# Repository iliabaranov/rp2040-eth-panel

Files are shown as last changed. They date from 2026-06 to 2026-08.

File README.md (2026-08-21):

# rp2040-eth-panel

Network-connected **two-button / dual-WS2812-ring operator panel** on a **Waveshare
RP2040-ETH** board. Debounces the buttons and streams press/release events over Ethernet
as line-delimited JSON; the host drives the two 16-LED rings and the illuminated
button's lamp over the same socket — with **robust firmware updates over Ethernet**
(no USB or physical access needed after the one-time install).

- **Board:** Waveshare RP2040-ETH (RP2040 + CH9120 UART↔Ethernet bridge; 4 MB flash)
- **Firmware:** C11 / Raspberry Pi Pico SDK 2.1.1
- **Network:** DHCP, TCP server on port 5005, line-delimited JSON
- **Inputs:** 2 momentary buttons (button 1 illuminated), 30 ms debounce (runtime-configurable)
- **Outputs:** 2× 16-LED WS2812 rings (color + brightness), button-1 lamp on/off (GP6)
- **OTA:** immutable bootloader + single app slot + network recovery (CRC32-verified)

The panel is a **host-commanded peripheral**: rings and lamp power up dark and the host
(normally the ROS 2 driver) re-sends desired state on every connect — see
[`docs/DESIGN.md`](docs/DESIGN.md) for why nothing is persisted to flash. Sibling
project of [`rp2040-eth-keypad`](../rp2040-eth-keypad) (same board, same OTA stack).

See [`docs/DESIGN.md`](docs/DESIGN.md), [`docs/OTA.md`](docs/OTA.md),
[`docs/BRINGUP.md`](docs/BRINGUP.md), and the CH9120/board datasheets in
[`docs/`](docs/).

## Repository layout
```
firmware/     the Pico SDK build (CMake root); COLCON_IGNORE keeps colcon out of it
  src/          application: net (CH9120), buttons, rings, status LED, protocol, ota
  bootloader/   immutable first-stage bootloader (boot select + OTA recovery receiver)
  linker/       app (0x10040000) and bootloader (0x10000000, 256 KB) memory maps
ros2/panel_driver/   ROS 2 (Humble) driver: button topics in, ring/lamp topics out
examples/     standalone single-file ROS 2 driver (run directly — no colcon build)
test/         pytest + ctypes tests for the pure logic (buttons/rings/protocol) + OTA sim
tools/        flash / monitor / OTA / provision / live & mock helpers
```

## Prerequisites
Pico SDK (`PICO_SDK_PATH` set), the ARM toolchain (`arm-none-eabi-gcc`), CMake, and
`picotool` **built with USB support** (needs `libusb-1.0-dev`; a `99-picotool.rules` udev
rule for VID `2e8a` enables non-root access). Python 3 + `pyserial` for the host tools.

On this machine the toolchain lives at:
```bash
export PICO_SDK_PATH=~/pico/pico-sdk
export PATH=~/pico/xpack-arm-none-eabi-gcc-13.2.1-1.1/bin:~/.local/bin:$PATH   # GCC 13.2 + picotool 2.1.1
```

## Build
```bash
cmake -S firmware -B build   # one-time configure
cmake --build build -j       # -> build/{bootloader,panel,apptest}.uf2 (+ .bin)
```

## Install (one time, over USB)
Flashes the immutable bootloader (`0x10000000`) + application (`0x10040000`). After this,
all firmware updates go over Ethernet.
```bash
tools/provision.sh          # forces BOOTSEL, loads both stages, reboots
```
If the board can't be reached (blank flash, no app), hold the **BOOTSEL** button while
plugging in USB, then run `tools/provision.sh`. On boot the WS2812 LED flashes the IP's
last octet (green = DHCP).

## Bench test (no network): RING_SELFTEST
```bash
cmake -S firmware -B build -DRING_SELFTEST=1 && cmake --build build -j && tools/flash.sh --no-build
```
Skips networking and cycles pure logical **RED 1 s → GREEN 2 s → BLUE 4 s** on both
rings — the distinct dwell times identify which channel is which, so a GRB/RGB swap is
obvious (fix via `RING_COLOR_ORDER_GRB` in `firmware/src/config.h`). Raw button edges echo on
USB serial and the lamp follows button 1, so the whole panel is verifiable with just
USB power. Rebuild without the flag for the normal firmware.

## Watch events / drive the panel live
Quickest way to confirm the panel works over Ethernet. Pure-Python stdlib, no ROS:
```bash
tools/panel_live.py <device-ip>      # e.g. tools/panel_live.py 10.74.29.13
```
Prints each button down/up as it happens **and** takes interactive ring/lamp commands
(e.g. set ring 1 red, lamp on) so both directions of the protocol are exercised from
one terminal. `tools/panel_watch.py` is the watch-only variant for passive logging. The
device IP is shown on USB serial and encoded by the WS2812 (last octet). (No hardware
yet? `tools/mock_panel_server.py` emits the same protocol on `127.0.0.1:5005`.)

> The CH9120 is a **single-client** TCP server — disconnect `panel_live.py` before
> starting the ROS driver (and vice versa); a second socket wedges the bridge.

## Update firmware over Ethernet (OTA)
```bash
cmake --build build -j                                  # build the new image
tools/ota_flash.py --host <device-ip> build/panel.bin
```
This asks the running app to reboot into recovery, streams the image in CRC-checked
chunks, verifies the whole image, and reboots into it — no USB, no buttons. A failed or
interrupted update can't brick the device: the immutable bootloader stays in network
recovery for a re-push (`--in-recovery` skips the app trigger).

The transfer is resilient to the CH9120's frameless byte-stream quirks: both ends
**resync to known token boundaries** (so stray/stale bytes from a dropped connection
can't desync the session), corrupt chunks are re-sent locally, and the whole flash
auto-retries on a fresh connection if the link blips (`--retries`, default 3). See
[`docs/OTA.md`](docs/OTA.md) → *Transport robustness*.

## Status LED (onboard WS2812, GP25)
| Color | Meaning |
|---|---|
| blue (solid) | app booted, bringing up the network |
| green, flashing digits | app running, **DHCP** mode (digits = IP's last octet) |
| amber, flashing digits | app running, **static** mode (digits = IP's last octet) |
| purple (solid) | bootloader recovery — waiting for / receiving an OTA |

> The color reflects the **configured IP mode**, not a live Ethernet link. The CH9120
> exposes no link/DHCP status to the RP2040 (its `LINK` pin drives the RJ45 jack LEDs,
> not a GPIO), and returns a cached IP even with no cable — so firmware can't detect
> "cable attached." Set the mode for your network via `NET_USE_DHCP` in `firmware/src/config.h`
> (no auto-fallback).

## ROS 2 driver (Humble)
[`ros2/panel_driver/`](ros2/panel_driver/) connects to the device's TCP/JSON server and
bridges it to topics:

| Topic | Type | Direction | Notes |
|---|---|---|---|
| `~/button1/pressed` | `std_msgs/Bool` | publish | latched (transient local) |
| `~/button2/pressed` | `std_msgs/Bool` | publish | latched (transient local) |
| `~/ring1/color` | `std_msgs/ColorRGBA` | subscribe | `a` = brightness 0..1 |
| `~/ring2/color` | `std_msgs/ColorRGBA` | subscribe | `a` = brightness 0..1 |
| `~/button1/light` | `std_msgs/Bool` | subscribe | illuminated button's lamp |

Parameters: `host`, `port` (default 5005), `reconnect_period`.

> **Warning:** `ColorRGBA.a` defaults to **0**, which means brightness 0 — a message
> with only `r/g/b` set shows nothing. Always set `a` (1.0 = full).

The driver owns desired state: it caches the last commanded ring colors and lamp state
and **re-sends them whenever the device reconnects** (every `hello` triggers this;
the driver waits ~1 s for the device's connect-time hello and requests one itself
if it doesn't arrive — it never fires on CH9120 batches whose TCPS status pin is
dead).

The driver also supervises the link itself: the CH9120 silently drops a displaced
client (no FIN/RST), which strands a naive client on a half-open socket. The driver
pings after 2 s of RX silence and declares the connection dead after 6 s without
**receiving** anything (`keepalive_period` / `liveness_timeout` parameters), then
reconnects and resyncs automatically — no manual restarts. Note this supervises but
does not repeal the single-client rule: two drivers pointed at one panel will
endlessly steal the slot from each other, visibly, in both logs. The firmware deliberately persists
nothing — see [`docs/DESIGN.md`](docs/DESIGN.md). Single TCP client only: stop
`panel_live.py` (and any other driver) before launching the driver.

### Standalone example (no build)
For a minimal, copy-pasteable starting point, [`examples/standalone_panel_driver.py`](examples/standalone_panel_driver.py)
is a ~100-line single-file driver you run directly — no colcon build, no package, no
launch file:
```bash
source /opt/ros/humble/setup.bash
python3 examples/standalone_panel_driver.py <device-ip>
ros2 topic echo /button1_pressed          # plain names: /button{1,2}_pressed, /ring{1,2}_color, /button1_light
```
It publishes only on a press (no latched startup state), so `echo` stays quiet until you
press. Use the `panel_driver` package above for production (auto-reconnect, desired-state
resync, latched state, clean shutdown).

## Tests
```bash
tools/test.sh      # fast: pure-logic host lib + pytest (buttons/rings/protocol)
tools/test_ota.sh  # OTA stress: real flasher vs. device+CH9120 simulator, fault-injected
```
`tools/test_ota.sh` runs hundreds of OTA pushes through a faithful CH9120-bridge
simulator with injected stale bytes, mid-transfer resets, and byte loss — the
regression guard for the transport-desync bug (multi-minute by design, no hardware).

## Recovery
- **App update failed / device in recovery:** re-run `tools/ota_flash.py` (it auto-detects
  recovery), or push with `--in-recovery`.
- **Device unresponsive:** press **RESET** (RUN button) to reboot into the last valid app.
- **Re-provision / bootloader update:** hold **BOOTSEL**, replug USB, run `tools/provision.sh`.
  USB BOOTSEL (mask ROM) is always available as the ultimate fallback.

## License
Apache License 2.0 — see [`LICENSE`](LICENSE).

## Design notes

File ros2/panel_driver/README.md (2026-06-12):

# panel_driver (ROS 2 Humble)

ROS 2 **Humble** (`rclpy`) driver for the RP2040-ETH operator panel (2 buttons —
one illuminated — and 2×16 WS2812 LED rings). Connects as a TCP client to the device's
line-delimited JSON server and bridges it to ROS topics in both directions.

> **Single TCP client only.** The CH9120 Ethernet bridge wedges if a second
> client connects. Do **not** run `tools/panel_live.py` (or any other tool
> talking to port 5005) while this driver is running.

## Topics

All names are node-relative (`~/...`); with the default node name they appear
under `/panel_driver/...`.

### Published

| topic | type | QoS | meaning |
|---|---|-----|---|
| `~/button1/pressed` | `std_msgs/Bool` | RELIABLE, TRANSIENT_LOCAL, depth 1 | button 1 state (latched) |
| `~/button2/pressed` | `std_msgs/Bool` | RELIABLE, TRANSIENT_LOCAL, depth 1 | button 2 state (latched) |

Button states are **latched**: late subscribers immediately receive the current
state. Initial states come from the device's `hello` line (sent on every
connect); after that, every `down`/`up` edge is published.

### Subscribed

| topic | type | meaning |
|---|---|---|
| `~/ring1/color` | `std_msgs/ColorRGBA` | ring 1 color + brightness |
| `~/ring2/color` | `std_msgs/ColorRGBA` | ring 2 color + brightness |
| `~/button1/light` | `std_msgs/Bool` | button 1 lamp (the illuminated button) |

> **⚠ The `a` channel is BRIGHTNESS, and it defaults to 0.0!**
> `r`, `g`, `b` are 0..1; `a` is brightness 0..1 where **`a=0` means the ring
> is OFF**. `ColorRGBA` zero-initializes `a`, so a sender that only sets
> `r/g/b` turns the ring off. Always set `a` explicitly (e.g. `a: 1.0`).

## Desired-state resync

The driver caches the last commanded ring colors and lamp state. On every
`hello` — i.e. every (re)connect, which covers device reboots, OTA updates and
cable blips — it re-sends all cached commands, so the panel always converges to
ROS's desired state. Commands published while disconnected are cached and
applied on the next reconnect.

## Parameters

| param | default | meaning |
|---|---|---|
| `host` | `''` | device IP (DHCP-assigned). **Required** — the node logs a fatal error and exits if empty. |
| `port` | `5005` | device TCP port |
| `reconnect_period` | `2.0` | seconds between reconnect attempts |

## Run

```bash
# In a ROS 2 Humble workspace (ros2/ as the src dir):
source /opt/ros/humble/setup.bash
colcon build --packages-select panel_driver
source install/setup.bash

ros2 launch panel_driver panel_driver.launch.py host:=<device-ip>
# or:
ros2 run panel_driver panel_driver --ros-args -p host:=<device-ip>
```

Watch the buttons (latched — you get the current state immediately):

```bash
ros2 topic echo /panel_driver/button1/pressed
```

Set ring 1 to orange at half brightness (note `a` is set!):

```bash
ros2 topic pub --once /panel_driver/ring1/color std_msgs/msg/ColorRGBA \
  "{r: 1.0, g: 0.25, b: 0.0, a: 0.5}"
```

Turn the button lamp on:

```bash
ros2 topic pub --once /panel_driver/button1/light std_msgs/msg/Bool "{data: true}"
```

## Tests

The protocol logic is a pure module ([`panel_driver/panel_protocol.py`](panel_driver/panel_protocol.py),
no `rclpy` import) and is unit-tested without a ROS graph. Run the tests with a
clean environment — a sourced ROS env injects pytest plugins that break
collection:

```bash
cd ros2/panel_driver
PYTHONPATH= PYTEST_DISABLE_PLUGIN_AUTOLOAD=1 python3 -m pytest test/
```

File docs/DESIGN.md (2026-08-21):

# RP2040-ETH Panel Controller — Design

Network-connected **two-button / dual-WS2812-ring operator panel** on a **Waveshare
RP2040-ETH** board (RP2040 + CH9120 UART↔Ethernet bridge). Debounces the buttons and
streams press/release events to a TCP client as line-delimited JSON; the host commands
the two LED rings and the illuminated button's lamp over the same socket. Firmware is
updated over Ethernet (no USB/physical access after the one-time install) — see
[`OTA.md`](OTA.md). Port of the `rp2040-eth-keypad` project to a different front-panel
peripheral set (same board, network layer, status LED, and OTA stack).

## Requirements (locked)

| Decision | Choice |
|---|---|
| Panel hardware | 2 momentary buttons (button 1 illuminated, lamp output) + 2× WS2812 rings (16 LEDs each) |
| MCU / board | **Waveshare RP2040-ETH** (RP2040 + **CH9120** UART↔Ethernet bridge) |
| Firmware stack | C11, Raspberry Pi Pico SDK 2.1.1 (CH9120 driven over UART1; no Ethernet lib) |
| Transport | TCP **server** on the device, port 5005, single control client |
| Wire format | Line-delimited JSON (one object per `\n`-terminated line), both ways |
| IP addressing  | **DHCP** by default (`NET_USE_DHCP`); static is a compile-time option. No auto-fallback — the CH9120 exposes no link/lease status the RP2040 can read, so the mode is chosen explicitly. |
| Host side | ROS 2 (Humble) driver `ros2/panel_driver` owns desired ring/lamp state  |
| State | **Nothing persisted to flash** — see *No flash persistence* below |

## Hardware

### Buttons
- Two momentary buttons wired **to GND**, read with internal pull-ups → **active-low**.
  No external parts needed.
- Button 1 is an **illuminated** button; its lamp is driven separately from GP6.
- Debounce default **30 ms** (`DEBOUNCE_MS_DEFAULT`), runtime-overridable via the
  `config` command. The first sample after boot **seeds** the debouncer state without
  emitting an edge, so a button held during power-up doesn't fire a phantom event (its
  state still reaches the host in the `hello` line).

### WS2812 rings (2× 16 LEDs)
- **Power from 5 V** (header pin 1 = VBUS), not 3.3 V. Data line via a **~330 Ω series
  resistor** close to the first LED.
- 3.3 V data into a 5 V-powered ring usually works; if colors glitch or the first LED
  misbehaves, add a **level shifter** (e.g. 74AHCT125) on the data line.
- Put **~1000 µF** of bulk capacitance across each ring's power feed.
- **Power budget:** worst-case full-white is ~60 mA/LED → **≈960 mA per 16-LED ring at
  5 V** (~1.9 A both rings). Mind the USB/5 V supply budget; typical indicator colors at
  partial brightness draw far less.
- Color order is per-chain: standard WS2812B rings latch **GRB**
  (`RING_COLOR_ORDER_GRB=1` default); the board's **onboard GP25 LED anomalously
  latches RGB** (verified by self-test in the keypad project). See *WS2812 byte order*.

### Button-1 lamp (GP6)
GP6 is a plain on/off 3.3 V GPIO output. Driving the lamp directly is fine only for a
low-current 3.3 V LED (**≲10 mA**). If the illuminated button's lamp needs more
current, or runs at 5/12/24 V, use a **transistor/MOSFET low-side driver** (gate/base
from GP6 with a series resistor + pulldown, lamp supply to its own rail).

## Pin map (Waveshare RP2040-ETH)

Reserved by the CH9120 bridge (fixed by the board), do not reuse:

| Signal | GPIO | Notes |
|---|---|---|
| UART1 TX → CH9120 RXD | GP20 | RP2040 transmits config/data |
| UART1 RX ← CH9120 TXD | GP21 | RP2040 receives data |
| CFG | GP18 | LOW = config mode |
| RST | GP19 | Active-low reset |
| TCPS | GP17 | LOW = TCP peer connected |

**Header reality (RP2040-ETH MINI):** the 24-pin header (P1) only breaks out
**GPIO0–9, 22, 26, 27, 28** (+ power/RUN). GP10–15 and GP25 are *not* on the header;
GP16–21 are the CH9120. Application pins are chosen from the broken-out set:

| Function | GPIO | Header pin | Notes |
|---|---|---|---|
| Ring 1 data | GP2 | 21 | via ~330 Ω series resistor |
| Ring 2 data | GP3 | 20 | via ~330 Ω series resistor |
| Button 1 | GP4 | 19 | illuminated button, to GND, internal pull-up (active-low) |
| Button 2 | GP5 | 18 | to GND, internal pull-up (active-low) |
| Lamp (button 1) | GP6 | 16 | plain on/off output, 3.3 V — see drive note above |
| Status LED | GP25 | — | onboard WS2812 (RGB byte order!) |

Power: **GND** on header pins 3/8/17/22; **VBUS 5 V** on header pin 1 (ring power and,
via a driver, the lamp supply).

### CH9120 networking
The RP2040 holds CFG low, sends config frames (`0x57 0xAB <cmd> <data>`) at 9600 baud to
set mode/IP/subnet/gateway/port and the data baud, commits (`0x0d` save, `0x0e`
execute+reset), releases CFG, and switches UART1 to 115200. Thereafter UART1 is a transparent pipe to
the TCP socket — the protocol layer just reads/writes bytes. `net_peer_connected()`
reflects the TCPS pin. See `firmware/src/net/net.c`.

## Software architecture

Clean separation: **pure logic** modules (no hardware, no SDK calls — host-testable)
behind thin **glue** that touches the SDK/GPIO/PIO/CH9120.

```
firmware/src/
  main.c                — super-loop: buttons -> events, dispatch commands, flush rings
  config.h              — compile-time defaults (pins, ring sizes, debounce, IP mode)
  buttons/
    buttons.h/.c        — PURE: per-button debounce + press/release edge events,
                          first-sample seeding (no phantom edge at boot)
    buttons_hw.c        — GLUE: GPIO init (pull-ups), raw active-low reads, lamp output
  rings/
    rings.h/.c          — PURE: per-ring color/brightness state, (c*brightness+127)/255
                          round-to-nearest scaling, GRB/RGB pixel-word packing, dirty flags
    rings_hw.c          — GLUE: PIO state machines, blocking FIFO pushes
  net/
    net.h/.c            — GLUE: CH9120 config over UART1 (mode/IP/port/baud), then
                          byte-stream read/write to the TCP socket; peer-connected pin
  protocol/
    protocol.h/.c       — PURE: JSON parse (commands) / format (events), schema
  status_led/           — onboard WS2812 (PIO): boot/mode/recovery indication
  ota/                  — flash layout, CRC32, boot-state, app-side update trigger
firmware/bootloader/    — immutable first stage: boot select + network OTA recovery
test/                   — pytest + ctypes against a host-built shared lib of the PURE
                          modules; OTA failure-injection suite (sim + real flasher)
```
The two-stage boot (immutable bootloader + single app slot) and the Ethernet update
protocol are documented separately in [`OTA.md`](OTA.md).

The pure modules take time as an argument (`now_ms`) and raw samples from the caller,
so debounce and rendering logic run identically on host and target.

### PIO allocation
One shared `ws2812` PIO program per block:

| PIO | SM | Output |
|-----|----|---|
| pio0 | sm0 | onboard status LED, GP25 (RGB order) |
| pio1 | sm0 | ring 1, GP2 (GRB order) |
| pio1 | sm1 | ring 2, GP3 (GRB order) |

The rings share a single program load in pio1; the status LED owns pio0 so the
bootloader (which links only the status LED) and the app never contend.

### Concurrency
Single-core cooperative super-loop on core0 at **~500 Hz** (2 ms tick): each pass
services the status LED, detects TCP peer connect edges (→ `hello`), samples and
debounces the buttons, accumulates inbound bytes into lines and dispatches complete
commands, and flushes dirty ring frames (the 2 ms gap between passes satisfies the
WS2812 >50 µs inter-frame latch). Deterministic and simple.

**Line framing is a deliberate upgrade over the keypad firmware**, which only
`strstr()`-scanned the inbound stream for the OTA trigger: the panel buffers bytes into
`\n`-terminated lines, parses each through `protocol.c`, and dispatches on the command
type — so every command (`ring`, `lamp`, `config`, `ping`, `ota`) gets real parsing,
acks, and error replies. Overlong lines are dropped with an `err` and the parser
resyncs at the next newline; a half-line left over from a previous connection is
discarded on peer reconnect.

## Wire protocol (line-delimited JSON over TCP, port 5005)

### Device → host (events)
```json
{"t":"hello","fw":"1.0.0","buttons":2,"rings":[16,16],"pressed":[false,false],"ip":"10.74.29.13"}
{"t":"btn","id":1,"e":"down","ms":123456}
{"t":"btn","id":1,"e":"up","ms":124102}
{"t":"ack","cmd":"ring"}
{"t":"err","msg":"bad ring cmd"}
```
The `hello` is sent on **every TCP peer connect** (TCPS pin edge) — firmware version,
ring sizes, and current debounced button states — so the host can resync after either
side restarts. This is the hook the ROS driver uses to re-push desired state.

**Do not rely on the unsolicited hello alone:** some CH9120 batches never assert the
TCPS pin (observed on a 2026 unit — the pin is actively driven but stays HIGH with a
live TCP connection), so the connect edge never fires. Hosts should wait ~1 s for the
connect-time hello and send `{"cmd":"hello"}` only if it doesn't arrive (fw ≥ 1.0.3
replies with the hello line) — this is what the ROS driver does. Don't send the
request immediately on connect: on TCPS-working units the device flushes its RX
buffer at the connect edge, and a line already in flight gets truncated to junk
(answered with `{"t":"err","msg":"no cmd"}`). A duplicate hello, if both fire, is a
harmless double resync.

### Host → device (commands)
```json
{"cmd":"ring","id":1,"r":255,"g":64,"b":0,"brightness":128}
{"cmd":"lamp","on":true}
{"cmd":"config","debounce_ms":30}
{"cmd":"ping"}
{"cmd":"hello"}
{"cmd":"ota"}
```
- `ring`: `id` 1–2; `r/g/b` 0–255; `brightness` 0–255. **Absent fields keep their
  current value** (e.g. brightness-only fades, color-only changes). The whole ring is
  one uniform color.
- `lamp`: button 1's illumination, on/off.
- `config`: `debounce_ms` 1–1000, applies immediately (not persisted).
- `ping`: liveness keepalive. The CH9120 drops a displaced client silently (no
  FIN/RST), so hosts must treat **received** traffic as the only liveness evidence
  and reconnect after an RX-silence timeout — the ROS driver pings after 2 s of
  silence and tears down after 6 s.
- `hello`: request the hello line; the reply is the hello event itself, not an ack.
- `ota`: ack, then reboot into bootloader recovery ([`OTA.md`](OTA.md)).
- Unknown/invalid commands → `{"t":"err",...}`; valid → `{"t":"ack",...}`.

## No flash persistence (deliberate)

Ring colors, brightness, lamp state, and the debounce override are **not persisted to
flash** — a deliberate deviation from our usual persist-user-settings rule for embedded
UIs. Rationale:

- The panel is a **host-commanded peripheral**, not a self-contained UI. The ROS 2
  driver is the single source of truth for desired state and **re-sends it on every
  reconnect** — the device emits `hello` on every TCP connect precisely to trigger
  that resync. Persisted device-side state would be stale the moment the driver
  reconnects, so it buys nothing.
- Ring commands can arrive at animation rates; writing each one to flash would **wear
  the sector for no benefit** (and stall the super-loop during erase).
- A defined dark power-on state is the safer default for an operator panel: a stale
  persisted "GO" green ring after a power cycle would be a false indication.

**Power-on state:** rings dark (brightness scale full, so the first color command shows
correctly), lamp off — until the host connects and commands otherwise.

## WS2812 byte order (gotcha) + self-test

The **onboard GP25 LED latches RGB** — a board anomaly verified by self-test in the
keypad project (`status_led.c` sends RGB). External ring modules are **standard GRB**;
`RING_COLOR_ORDER_GRB` in `config.h` defaults to 1. Don't "fix" one by breaking the
other — the orders are per-chain and `rings.c` packs them independently of the status
LED.

To verify a new ring batch:
```bash
cmake -S firmware -B build -DRING_SELFTEST=1 && cmake --build build -j
```
The self-test build skips networking and cycles pure logical **RED 1 s / GREEN 2 s /
BLUE 4 s** on both rings — watch the **dwell time** to identify which channel is
actually lit (a GRB ring driven as RGB shows green during the 1 s "RED" phase). It also
echoes raw button edges on USB serial and drives the lamp from button 1, so the full
panel is bench-testable with no network.

## Configuration
Compile-time defaults in `firmware/src/config.h`: pins, ring LED counts (`RING1_NUM_LEDS` /
`RING2_NUM_LEDS`, both 16), color order, debounce 30 ms, IP mode `NET_USE_DHCP` +
static IP/mask/gw for the static option, TCP port 5005. The only runtime override is
`debounce_ms` via the `config` command (intentionally not persisted — see above).

## Testing
`pytest` drives the pure modules through `ctypes` against a host-compiled shared lib
(`tools/test.sh`):
- buttons — debounce stable-time gating, first-sample seeding (no boot edge), edge timing.
- rings — keep-current semantics of absent fields, brightness scaling rounding,
  GRB/RGB packing, dirty-flag behavior.
- protocol — round-trip command parse + event format, malformed input, absent fields → -1.

Hardware glue (GPIO, PIO, CH9120) is verified on-target (`RING_SELFTEST`,
[`BRINGUP.md`](BRINGUP.md)), not unit tested. The OTA path additionally has a host-side
failure-injection suite (a faithful device+CH9120-bridge simulator driven by the real
flasher) — see [`OTA.md`](OTA.md) and `tools/test_ota.sh`.

## Open / deferred
- Per-LED ring patterns (spinner/progress) — current protocol is one uniform color per
  ring; per-LED frames would need a bulk command and a faster dirty path.
- TLS / auth on the socket (currently trusted LAN assumption).
- Brightness-limited "panel test" command (all-white at capped brightness) for field
  diagnostics within the power budget.

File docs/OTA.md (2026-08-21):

# Over-Ethernet firmware update (OTA)

Robust field updates for the RP2040 over the CH9120 Ethernet bridge, with the
guarantee that **a failed update can never make the device impossible to re-flash
over Ethernet.** This is the same two-stage OTA stack as the sibling
`rp2040-eth-keypad` project (same board, same transport), carried over intact.

## Guarantee & how it holds
The bootloader is the **trust anchor**: it brings up Ethernet and can receive a new
image entirely on its own, and it is **never overwritten by an update**. Therefore,
no matter how an app update fails, the device still boots the bootloader, which still
talks Ethernet and still accepts a fresh image.

- Decisions (chosen 2026): **single app slot + network recovery**, **CRC32 integrity**,
  **immutable bootloader (provisioned once over USB)**.
- Ultimate fallback: the RP2040 mask-ROM **USB BOOTSEL** is always available (physical),
  but the design aims to never need it — Ethernet recovery is the normal safety net.

## Flash map (4 MB W25Q32, XIP base 0x10000000)
| Region | XIP address | Flash offset | Size | Notes |
|---|---|---|---|---|
| Bootloader | 0x10000000 | 0x000000 | 256 KB | immutable; own boot2, CH9120, recovery, flash writer |
| App slot | 0x10040000 | 0x040000 | 0x3BE000 (~3.74 MB) | single application image |
| Boot-state A | 0x103FE000 | 0x3FE000 | 4 KB | redundant, CRC'd |
| Boot-state B | 0x103FF000 | 0x3FF000 | 4 KB | redundant, CRC'd |

App images are ~100–200 KB, so the slot is far larger than needed (room to grow).
Definitions shared by bootloader and app live in `firmware/src/ota/layout.h`.

## Images & jump
- Both bootloader and app are normal Pico-SDK binaries (each has its own boot2). The
  **bootrom** only runs the bootloader's boot2 at 0x10000000.
- The app is **linked at 0x10040000**. The bootloader (XIP already configured) hands
  off by: validating the app, `__disable_irq()`, deinit of peripherals it used, set
  `VTOR = 0x10040100` (app vector table, after the app's unused boot2), load MSP from
  `[0x10040100]`, jump to reset vector `[0x10040104]`.

## Boot-state (power-fail-safe)
Two 4 KB sectors written ping-pong (write the newer record to the older sector) so an
interrupted write always leaves the previous valid record intact.
```
struct boot_state {
  uint32_t magic;        // 'B''S''T''1'
  uint32_t seq;          // monotonically increasing; higher = newer
  uint32_t app_len;      // bytes of the app image
  uint32_t app_crc32;    // CRC32 over [APP_BASE .. APP_BASE+app_len)
  uint8_t  app_valid;    // image fully received + CRC-verified at flash time
  uint8_t  app_confirmed;// app proved healthy (network up) post-update
  uint8_t  boot_attempts;// boots since flashed without a confirm
  uint8_t  _pad;
  uint32_t crc32;        // CRC32 over the struct above
};
```
The CRC32 is the standard zlib polynomial — `zlib.crc32()` on the host computes
bit-identical values, which is what `tools/ota_flash.py` uses.

## Boot decision (bootloader)
1. If watchdog `SCRATCH0 == ENTER_UPDATE_MAGIC` (`0x0B00B1E5`) → **recovery** (app
   explicitly requested it).
2. Else if `!app_valid` or slot CRC re-check fails → **recovery** (no good image).
3. Else if `app_confirmed` → **boot app** (reset boot_attempts).
4. Else (valid but unconfirmed — a freshly flashed image): if `boot_attempts >= 3` →
   mark `app_valid=0` → **recovery**; otherwise `boot_attempts++`, persist, **boot app**.

The app, once it has booted and brought the network up successfully, calls
`ota_confirm()` which sets `app_confirmed=1`, `boot_attempts=0`. So a CRC-valid image
that crashes or can't network is auto-dropped to recovery after 3 boots.

## Recovery / update protocol (binary, little-endian, over the CH9120 TCP socket)
The CH9120 bridges TCP↔UART, so this runs over the same socket the app uses. Each
message starts with a 4-byte magic; all integers are little-endian u32. Lock-step:
each DATA waits for its ACK so the sender pauses during flash erase/program (no UART
overrun). Both ends resync to these magics (see *Transport robustness* below).

| Step  | Host → device | Device → host |
|---|---|---|
| SYNC  | `"RP2BOOT1"` (8 bytes) | `"BLOK"` + `slot_size` + `max_chunk` (or no reply if it's the app) |
| BEGIN | `"BEGN"` + `app_len` + `app_crc32` | `"OKER"` after erasing the slot (`"ERSZ"` if size is bad) |
| DATA  | `"DATA"` + `off` + `len` + `chunk_crc32` + payload | `"DACK"` + `off` (or `"DNAK"` + `off` to resend) |
| END | `"END!"` | flush XIP, verify whole-slot CRC == `app_crc32`, write boot-state → `"DONE"` (or `"ECRC"`) |
| GO | `"GO!!"` | `"BYE!"`, then reboot into the app |

Entering update mode from the running app: the app receives `{"cmd":"ota"}` on its
normal JSON socket — parsed as a first-class command by the protocol module
(`proto_parse` → `CMD_OTA`, like any other command; the keypad's app merely
`strstr()`-scanned the stream for it) → acks `{"t":"ack","cmd":"ota"}` → writes
`SCRATCH0 = ENTER_UPDATE_MAGIC` → `watchdog_reboot()`. The host flasher waits for that
ack and then reconnects to the same IP and runs SYNC (re-triggering if the ack was
lost — see *Transport robustness*).

## Failure handling (why each case stays recoverable)
- **Dropped/garbled transfer or bad chunk CRC** → image never CRC-verifies → `app_valid`
  stays 0 → bootloader remains in recovery → re-push.
- **Power loss mid-erase/program** → slot partially written, `app_valid` not set (or slot
  CRC re-check fails) → recovery on next boot.
- **Power loss mid boot-state write** → ping-pong leaves the prior record valid.
- **Valid CRC but the new app crashes / can't network** → never confirmed → after 3 boots
  bootloader drops to recovery.
- **Bootloader corruption** → not written during OTA (immutable); USB BOOTSEL recovers.

## Implementation notes (verified end-to-end over Ethernet on this board family)
- **Flash size:** the boot-state sectors live near the top of the 4 MB chip
  (`0x3FE000`), so the build MUST set `PICO_FLASH_SIZE_BYTES=4194304` — otherwise the
  Pico SDK's `flash_range_erase`/`program` `hard_assert(offs <= PICO_FLASH_SIZE_BYTES)`
  (default 2 MB) panics. (Set in the top-level `CMakeLists.txt`.)
- **App hand-off:** `jump_to_app` disables NVIC IRQs + SysTick but must **not** set
  PRIMASK (`cpsid i`) — the app's early init (`sleep_ms`/stdio) relies on the timer-alarm
  IRQ, so global interrupts must stay enabled.
- **Recovery is fast:** recovery does *not* reconfigure the CH9120; it light-attaches to
  the chip's existing config (`net_attach_data_mode()` — UART at the data baud, CFG high).
  The CH9120 keeps its config + DHCP lease across an RP2040-only reboot, so recovery comes
  up in <1 s and the host reconnects to the same IP.
- **Whole-image CRC at END:** flush the XIP cache, then read via the normal cached alias.
  (Reading the non-cached alias left XIP in a streaming mode that stalled the subsequent
  `flash_range_erase`.)
- **Host flasher:** sends the `{"cmd":"ota"}` trigger on the *same* socket as the SYNC
  probe — the CH9120 is a single-client TCP server and a second socket to a running app
  wedges it.

## Transport robustness (CH9120 is a frameless byte stream)
The CH9120 is a transparent TCP↔UART bridge with **no message framing** and a
single-client server that buffers across connections. Two field-failure classes came
from this, both now defended on *both* ends:

- **Framing desync from stray/stale bytes.** A dropped or retried connection (e.g. the
  host's `ensure_recovery` probing SYNC) can leave bytes buffered in the bridge that
  arrive on the *next* connection, or a late duplicate response can precede the one
  expected. If either end consumed a fixed 4 bytes as "the next token", a single
  misaligned byte shifted *all* subsequent frames — so the push timed out at a
  *random* phase (this is exactly why the observed failure point moved between BEGIN
  and END across runs). **Fix:** both ends **resync to a known token** by sliding a
  4-byte window one byte at a time until a valid command/response magic appears
  (device: `read_command` in `recovery.c`; host: `read_token` in `ota_flash.py`), and
  the host **drains** stale bytes before each phase. Stray bytes are now skipped, not
  fatal.
- **Lost bytes / link blips.** A corrupted chunk fails its CRC → `DNAK` → the host
  **re-sends that chunk** (cheap, local recovery, retried generously). A connection-level
  fault (peer close, token timeout) instead propagates to the host's **whole-flash
  retry**, which restarts from SYNC on a fresh connection — safe because a partially
  written slot never sets `app_valid`, so the bootloader simply stays in recovery.
- **Lost update trigger.** Just after a reboot the app spends ~10 s reconfiguring the
  CH9120 and isn't reading the socket, so a blind one-shot `{"cmd":"ota"}` is easily
  dropped. The host's `ensure_recovery()` therefore treats **SYNC as the source of
  truth**: it re-probes and **re-sends the trigger, waiting for the app's ack**, until
  recovery actually answers. (The old code assumed a failed attempt had already reached
  recovery and skipped re-triggering — which stalled whenever the trigger was lost in
  that window. Sending the trigger to a device already in recovery is harmless: the
  receiver resyncs past the JSON.)

**Hardware-verified** in the sibling keypad project (identical board, bootloader, and
transport): 8 consecutive no-touch OTA cycles over Ethernet (alternating two build
versions), each confirmed end-to-end via the recovery serial trace — `BEGIN` CRC ==
pushed CRC, `END verify` match, `boot_state written`, `DONE`, reboot into the pushed
version, `app confirmed healthy` — with no USB and no human intervention. The panel's
own on-board OTA cycle is step 7 of [`BRINGUP.md`](BRINGUP.md).

**Testing:** `test/test_ota_flash.py` runs the real host flasher against a faithful
device+CH9120 simulator (`test/ota_sim.py`) across **hundreds of pushes** with injected
faults — stale prefixes (incl. duplicate SYNC), mid-transfer connection resets, and
random byte loss — asserting a byte-exact image lands every time the faults are
individually recoverable. This is the regression guard for the desync bug.

## Development / recovery notes
The bootloader brings up USB stdio in the recovery path for diagnostics; the normal boot
path stays USB-free for a clean, fast hand-off. If the board becomes unresponsive, press
**RESET** (RUN button) to reboot into the last valid app; **BOOTSEL** + USB is the
ultimate fallback for (re)provisioning. `tools/ota_flash.py --host <ip> build/panel.bin`
performs the full cycle; `--in-recovery` skips the app trigger when the device is
already in recovery.

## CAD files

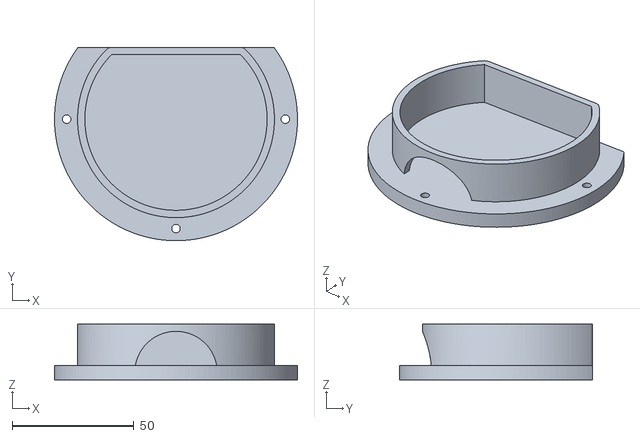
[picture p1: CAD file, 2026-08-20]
lid with stabilizer.stl
100.0 x 79.5 x 23.0

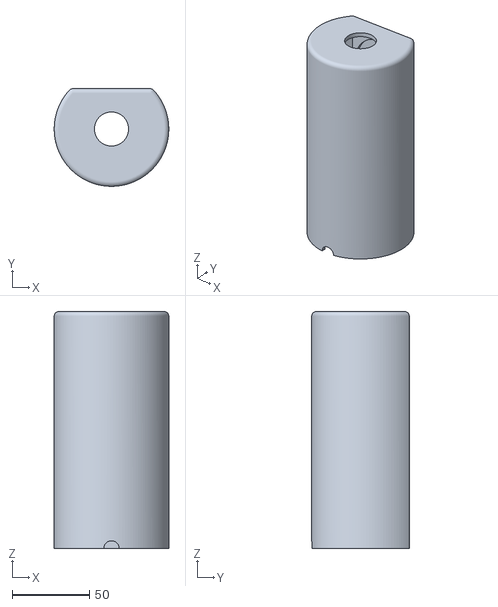
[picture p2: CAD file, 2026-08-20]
Casing 1 button.stl
74.0 x 63.0 x 153.0

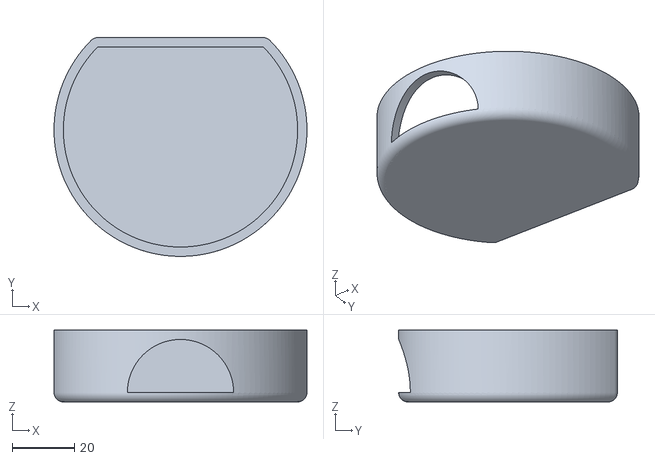
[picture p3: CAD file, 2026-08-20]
lid.stl
81.0 x 70.0 x 23.0

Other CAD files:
Casing.FCStd
Top Casing.step
Casing.stl

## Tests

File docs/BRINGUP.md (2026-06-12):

# Bring-up record

Hardware verification for the panel build (Waveshare RP2040-ETH + 2 buttons + 2× 16-LED
WS2812 rings), wired per [`DESIGN.md`](DESIGN.md).

**Status: brought up and verified on hardware 2026-06-12.** Device on DHCP at
**192.0.2.50** (MAC `AA:BB:CC:12:34:56`), TCP server on port 5005. Currently running
**v1.0.2**, deployed entirely over Ethernet (OTA). Results below; a few formal sub-steps
were not separately run and are noted as such.

Tooling: `tools/provision.sh` (one-time USB install), `tools/monitor.py` (serial),
`tools/ota_flash.py` (Ethernet updates), `tools/panel_live.py` (live events +
interactive commands), `tools/test.sh` / `tools/test_ota.sh` (host tests).

Build environment on the dev machine (no system Pico install):
```bash
export PICO_SDK_PATH=$HOME/pico/pico-sdk
export PATH=$HOME/.local/bin:$HOME/pico/xpack-arm-none-eabi-gcc-13.2.1-1.1/bin:$PATH
```
A `udev` rule `/etc/udev/rules.d/99-picotool.rules` (MODE 0666, VID 2e8a) grants non-root
USB access; otherwise `picotool` needs `sudo`.

## 1. Provision over USB ✅
`tools/provision.sh` loaded bootloader → `0x10000000` and panel → `0x10040000`, board
rebooted. Both flash writes hit 100%, exit 0.

**Result:** PASS (2026-06-11).

## 2. Serial boot banner ✅
Captured by resetting with `tools/monitor.py`-style capture attached (banner prints once
~1.5 s after reset; steady state is silent except `[btn]` lines):
```
=== rp2040-eth-panel v1.0.0 (CH9120) ===
[net] CH9120 mode=0 ipmode=DHCP port=5005
[net] MAC AA:BB:CC:12:34:56
[net] IP 192.0.2.50  (connect: tcp 192.0.2.50:5005)
[main] panel up: buttons GP4/GP5, lamp GP6, rings GP2/GP3 (16/16 LEDs)
```
Note: the Pico enumerates as `/dev/ttyACM1` here (`/dev/ttyACM0` is an unrelated 1a86
device) — match by USB VID 2e8a.

**Result:** PASS.

## 3. RING_SELFTEST — color-order check ⚠️ (not formally run)
Not run as the formal `-DRING_SELFTEST=1` dwell-time check. Rings were instead verified
live via ROS `ColorRGBA` commands (acked by device, colors confirmed by operator), so the
default `RING_COLOR_ORDER_GRB=1` is correct for these rings in practice. If a ring ever
shows wrong colors, run the formal self-test and flip the macro.

**Result:** rings functional (colors correct via commands); formal self-test not separately run.

## 4. Button + lamp bench check ✅
Both buttons produce clean events; the lamp (GP6) and both rings respond to commands.
Raw device stream during presses:
```
{"t":"btn","id":1,"e":"down"} / {"e":"up"}      ← button 1
{"t":"btn","id":2,"e":"down"} / {"e":"up"}      ← button 2
```
Confirms GP4/GP5 → GND wiring, software pull-ups, active-low read (no inversion), and the
GP6 lamp output.

**Result:** PASS (both buttons + lamp).

## 5. DHCP + status-LED octet ✅ (octet not visually checked)
DHCP lease `192.0.2.50` confirmed via the serial banner. The onboard WS2812 octet
flash was not visually inspected, but the IP read-back and TCP reachability confirm
networking. Color reflects configured mode (green = DHCP), not link state.

**Result:** PASS (DHCP/IP); LED octet not separately observed.

## 6. panel_live / protocol over Ethernet ✅
Over TCP to `:5005`: `hello` on connect; `ping`/`ring`/`lamp` → matching `ack`; invalid
ring id → `{"t":"err","msg":"bad ring cmd"}`; unknown verb → `{"t":"err","msg":"unknown cmd"}`.
Hello is re-sent on every reconnect. (`config debounce_ms` runtime change not separately
exercised; covered by host tests.)

**Result:** PASS.

## 7. OTA cycle ✅ (interrupted-push covered by sim, not on hardware)
Two full no-touch Ethernet updates verified end-to-end:
- v1.0.0 → **v1.0.1** (USB still attached): 45684 B streamed, CRC-verified, rebooted.
- v1.0.1 → **v1.0.2** (USB **disconnected**, Ethernet-only): same, confirmed via `hello`
  reporting `fw=1.0.2`.
Each rebooted into the new image on the same IP and confirmed healthy (no revert to
recovery). The interrupted/fault-injected path was not exercised on hardware but is the
job of `tools/test_ota.sh` (7/7 pass: stale bytes, mid-transfer resets, byte loss).

**Result:** PASS (OTA over Ethernet, USB-free).

## 8. ROS 2 driver smoke ✅
`ros2/panel_driver` (Humble, `host:=192.0.2.50`): connected, logged `hello fw=1.0.2`,
both `~/button1/pressed` and `~/button2/pressed` published `true`/`false` on press/release
(latched initial state from hello); `ColorRGBA` ring commands and `Bool` lamp commands
acked by the device. The standalone example (`examples/standalone_panel_driver.py`) was
also verified after fixing its socket-timeout bug (see commit history).

**Result:** PASS (package driver + standalone example).

## Host test suites (no hardware) ✅
- `tools/test.sh` → 34 passed (buttons / rings / protocol pure logic via ctypes).
- `tools/test_ota.sh` → 7 passed (OTA transport fault-injection, ~5 min).
- `ros2/panel_driver` pytest → 15 passed (pure protocol helpers).

## Board-level field gotchas (carried over from the keypad bring-up — same board)
- **Liveness = TCP connect to port 5005, never ping.** The CH9120 answers ICMP itself,
  independent of the RP2040 — a dead app still pings.
- **Single TCP client.** A second concurrent connection (a stray `panel_live.py`, `nc`,
  or a *leftover* driver process) wedges the bridge; a new driver then silently fails to
  connect and publishes nothing. Check `ps aux | grep panel` / `ros2 node list`. NOTE: a
  backgrounded `ros2 run` that is SIGTERM'd can leave its node child alive holding the
  socket — `kill -9` the PID. Foreground Ctrl-C shuts down cleanly.
- `picotool reboot` is a **no-op without `-f`** when a USB serial connection is present.
- RP2040 USB-CDC drops stdout written before a host opens the port with **DTR asserted**,
  and the app is silent when idle — attach `tools/monitor.py` (asserts DTR) before reset.
- The standalone example publishes **only on a press** (no latched startup state), so
  `ros2 topic echo` stays quiet until you actually press. Its topics are plain
  (`/button1_pressed`, …); the package driver's are namespaced (`/panel_driver/button1/pressed`).
- A sourced ROS environment puts broken pytest plugins on the path; the test scripts run
  with `PYTHONPATH=` and `PYTEST_DISABLE_PLUGIN_AUTOLOAD=1` (`tools/test.sh`).
- CH9120 config baud is fixed at 9600; the data path runs at 115200. The leased IP is read
  back from the CH9120 (cmd `0x61`) for the LED octet + logging.
- No link/DHCP status is readable by the RP2040 (the CH9120 `LINK` pin drives the RJ45
  LEDs); the status LED shows the **configured** IP mode and a possibly cached IP.

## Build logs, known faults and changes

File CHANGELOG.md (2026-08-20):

# Changelog

## v1.0.3 — 2026-08-19 (first public release)

### Firmware
- **New `{"cmd":"hello"}` request verb** — the device replies with the hello
  line (fw version, ring sizes, current button states). Motivation: some
  CH9120 batches never assert the TCPS status pin, so the unsolicited
  connect-time hello never fires on those units and hosts got no state
  resync. Diagnosed on real hardware: the pin is actively driven HIGH by the
  CH9120 even with a live TCP connection (not a solder/trace fault).

### ROS 2 driver
- **Hello request as a delayed fallback** — the driver waits ~1 s for the
  device's connect-time hello and requests one only if it hasn't arrived.
  Sent in the same instant as the connect, the request races the device's
  connect-edge RX flush on TCPS-working units and arrives truncated (the
  device errs `no cmd` on every connect).
- **RX-fed liveness keepalive** — the CH9120 serves one TCP client and
  silently drops a displaced one (no FIN/RST), stranding a naive client on a
  half-open socket: `recv()` times out quietly forever while sends vanish
  into the local TCP buffer, so the driver looked connected while the device
  had stopped listening. The driver now pings after 2 s of receive-silence
  and declares the connection dead after 6 s without receiving anything,
  then reconnects and resyncs desired state automatically (~8 s worst-case
  outage, no manual restart). Liveness counts received traffic only —
  successful sends prove nothing on a half-open socket. Bonus observed on
  hardware: the keepalive traffic also prevents displacement — the CH9120
  keeps the data path on the actively-talking client; only idle clients lose
  it. New parameters: `keepalive_period` (2.0 s), `liveness_timeout` (6.0 s).
- The standalone example requests the hello after a short grace period; the
  mock panel server answers `hello` and `ping` like the real firmware.

### CAD
- One-button panel variant: new top casing (single top button, front
  illuminated button omitted), lid with stabilizer. The firmware needs no
  change for this variant — button 1 reads not-pressed and the lamp output
  is left unconnected.

### Protocol notes for host implementers
- Do not rely on the unsolicited connect-time hello; request one if none
  arrives shortly after connecting.
- Never send in the same instant as the connect — the device's connect-edge
  RX flush can truncate a line already in flight.
- Treat received traffic as the only liveness evidence and reconnect after
  an RX-silence timeout.

## v1.0.2 — 2026-06-12
- Verified the OTA-only update path (Ethernet, no USB attached).
- Standalone example fix: clear the socket timeout inherited from
  `create_connection` so the reader thread survives idle periods.
- Documentation accuracy fixes; hardware bring-up record in
  `docs/BRINGUP.md`.

## v1.0.1 — 2026-06-11
- 25 confirmed fixes from an adversarial review, including: UART RX IRQ ring
  buffer (32-byte FIFO overrun at 115200 baud), WS2812 inter-frame latch
  gap, button state/event desync, button-held-at-boot seeding before hello,
  overlong-line discard state, driver socket teardown and thread join on
  shutdown, send-failure resync.

## v1.0.0 — 2026-06-11
- Initial release: immutable bootloader with OTA recovery (app at
  0x10040000, CRC-verified updates over Ethernet), panel application
  (2 buttons, 2×16-LED WS2812 rings, button lamp), CH9120 TCP:5005
  line-delimited JSON protocol, ROS 2 Humble driver package, standalone
  example, mock device server, host-side test suite, USB provisioning and
  OTA tools.

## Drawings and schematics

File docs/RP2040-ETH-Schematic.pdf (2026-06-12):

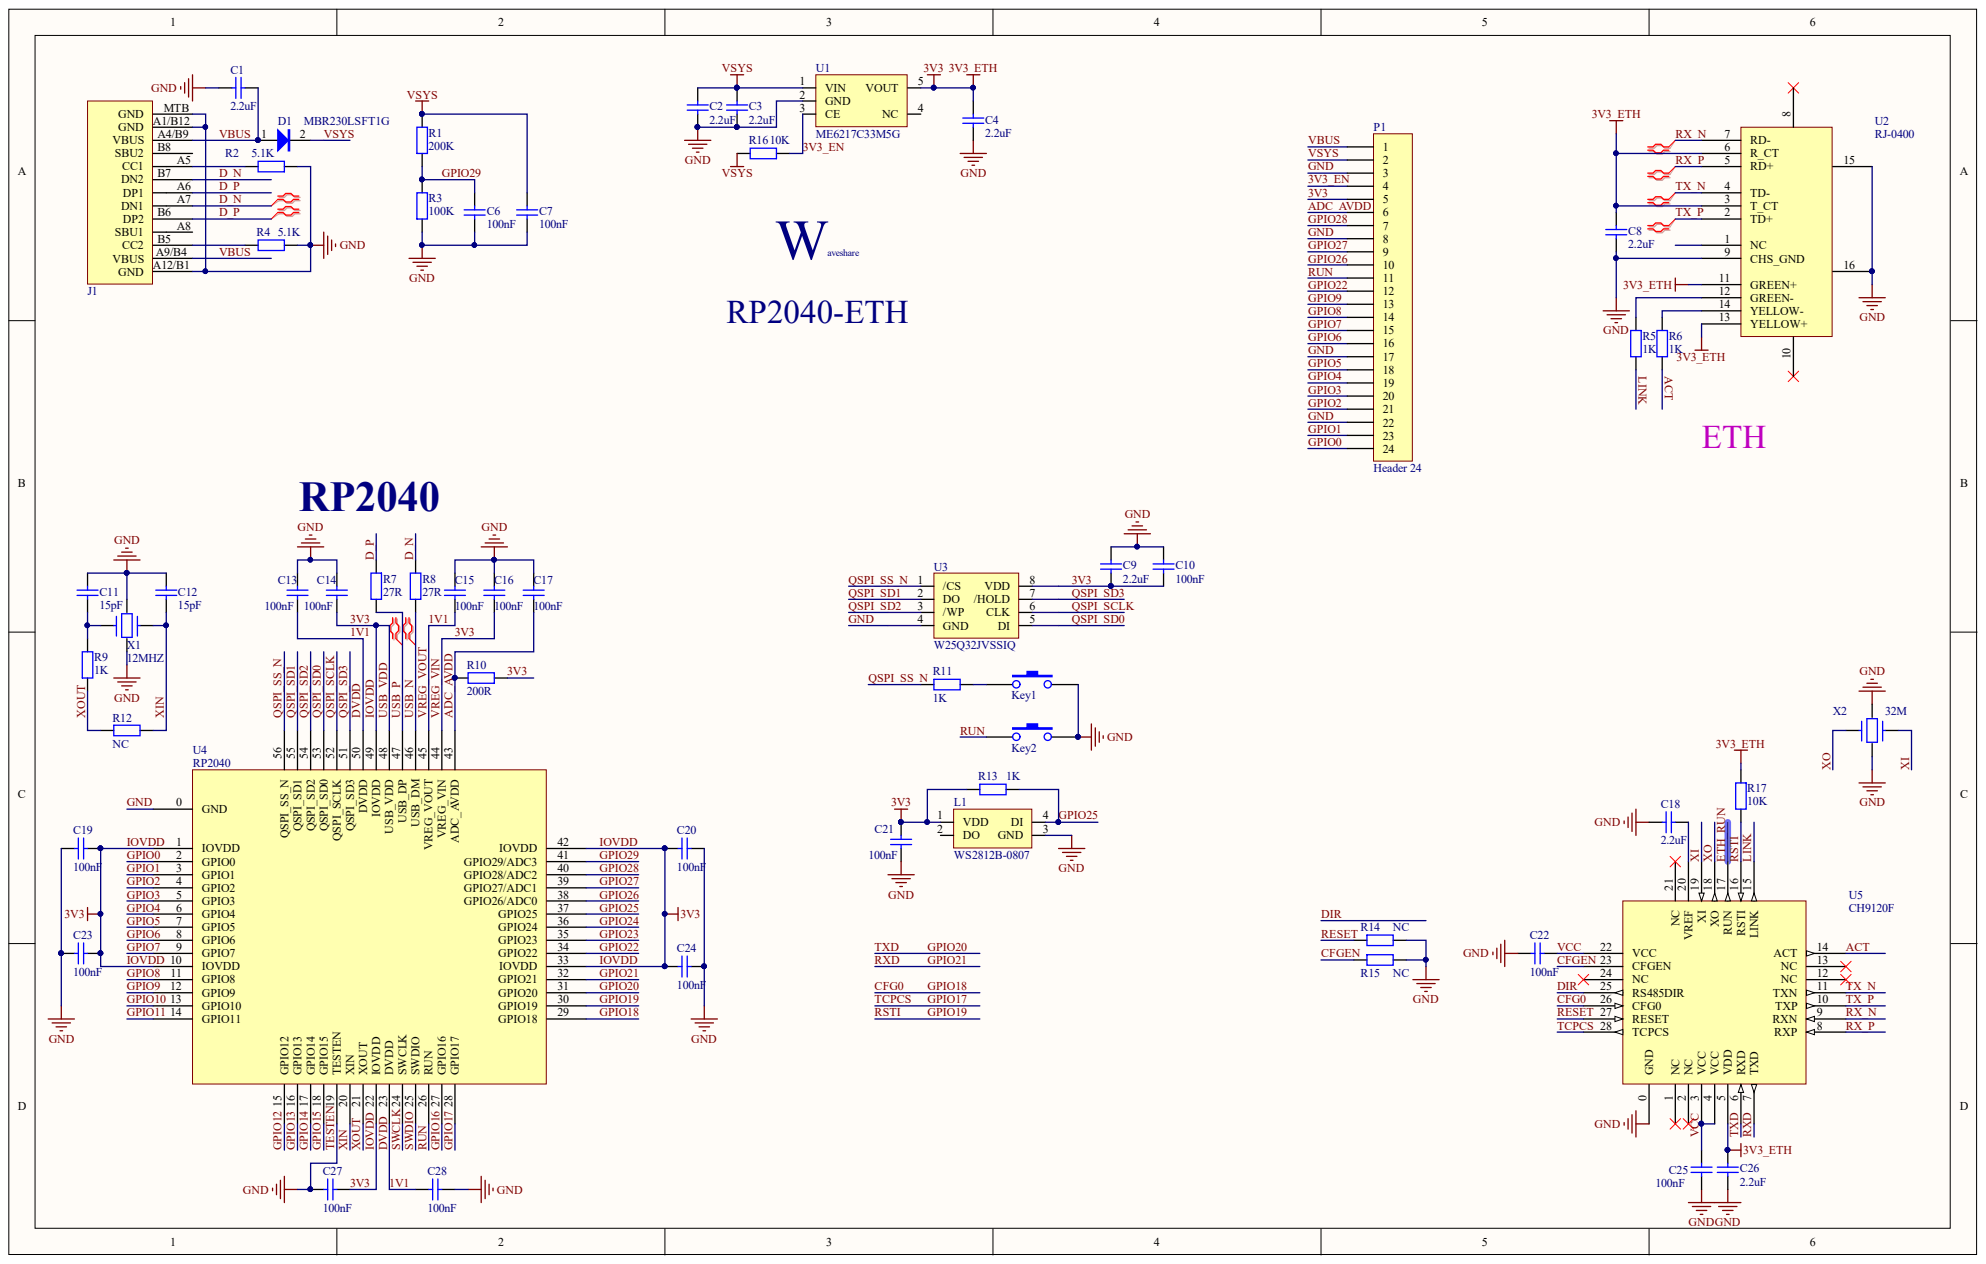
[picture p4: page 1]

LINK 15 RSTI 16 RUN 17 XO 18 XI 19 VREF 20 NC 21

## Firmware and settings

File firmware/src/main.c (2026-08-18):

/*
 * rp2040-eth-panel — application entry point (Waveshare RP2040-ETH).
 *
 * Two-button / dual-WS2812-ring operator panel. Brings up the CH9120 Ethernet
 * bridge, indicates state on the onboard WS2812 (green=DHCP / amber=static,
 * flashing the IP's last octet), confirms the running image to the bootloader,
 * then runs the super-loop: debounce the buttons and stream press/release events
 * as JSON to the TCP client, execute ring/lamp/config commands, and handle the
 * `{"cmd":"ota"}` trigger (reboot into OTA recovery).
 *
 * On each TCP peer connect (TCPS pin edge) the device sends a hello line with
 * firmware version, ring sizes, and the current button states, so the host can
 * resync state after either side restarts. Hosts should also request it with
 * {"cmd":"hello"} after connecting: some CH9120 batches never assert TCPS, so
 * the unsolicited hello may never arrive.
 */
#include <stdio.h>
#include <string.h>

#include "pico/stdlib.h"

#include "config.h"
#include "net/net.h"
#include "status_led/status_led.h"
#include "ota/ota_app.h"
#include "buttons/buttons.h"
#include "buttons/buttons_hw.h"
#include "rings/rings.h"
#include "rings/rings_hw.h"
#include "protocol/protocol.h"

#if RING_COLOR_ORDER_GRB
#define RING_ORDER RING_ORDER_GRB
#else
#define RING_ORDER RING_ORDER_RGB
#endif

static rings_t    s_rings;
static buttons_t  s_buttons;
static uint16_t   s_debounce_ms = DEBOUNCE_MS_DEFAULT;

/* Push any dirty ring frames. The 2 ms loop tick between passes satisfies the
 * WS2812 >50 us inter-frame latch. */
static void rings_flush(void) {
    uint32_t words[RING_MAX_LEDS];
    for (int i = 0; i < RING_COUNT; i++) {
        if (!s_rings.dirty[i]) continue;
        int n = rings_render(&s_rings, i, RING_ORDER, words, RING_MAX_LEDS);
        if (n < 0) continue; /* render failed (LED count > RING_MAX_LEDS) — keep
                              * dirty so a corrected frame still gets pushed later */
        rings_hw_push(i, words, n);
        rings_clear_dirty(&s_rings, i);
    }
}

static void send_line(const char *line, int len) {
    if (len > 0) net_write((const uint8_t *)line, len);
}

static void send_ack(const char *cmd) {
    char line[48];
    send_line(line, proto_fmt_ack(line, sizeof(line), cmd));
}

static void send_err(const char *msg) {
    char line[80];
    send_line(line, proto_fmt_err(line, sizeof(line), msg));
}

static void send_hello(const net_status_t *st) {
    char ip[16];
    snprintf(ip, sizeof(ip), "%d.%d.%d.%d", st->ip[0], st->ip[1], st->ip[2], st->ip[3]);
    const uint16_t nleds[2] = { RING1_NUM_LEDS, RING2_NUM_LEDS };
    const bool pressed[2] = { buttons_pressed(&s_buttons, 0),
                              buttons_pressed(&s_buttons, 1) };
    char line[160];
    send_line(line, proto_fmt_hello(line, sizeof(line), FW_VERSION, nleds, pressed, ip));
}

static void dispatch(const char *line) {
    proto_cmd c;
    if (!proto_parse(line, &c)) {
        send_err("no cmd");
        return;
    }
    switch (c.type) {
    case CMD_RING:
        if (rings_set(&s_rings, c.id - 1, c.r, c.g, c.b, c.brightness)) {
            send_ack("ring");
        } else {
            send_err("bad ring cmd");
        }
        break;
    case CMD_LAMP:
        if (c.on == 0 || c.on == 1) {
            lamp_hw_set(c.on == 1);
            send_ack("lamp");
        } else {
            send_err("bad lamp cmd");
        }
        break;
    case CMD_CONFIG:
        if (c.debounce_ms >= 1 && c.debounce_ms <= 1000) {
            s_debounce_ms = (uint16_t)c.debounce_ms;
            buttons_set_debounce(&s_buttons, s_debounce_ms);
            send_ack("config");
        } else {
            send_err("bad debounce_ms");
        }
        break;
    case CMD_PING:
        send_ack("ping");
        break;
    case CMD_HELLO:
        /* Host-requested hello. The reply IS the hello line (no ack). Needed
         * because some CH9120 batches never assert TCPS, so the edge-triggered
         * hello below cannot be relied on by hosts. */
        send_hello(net_status());
        break;
    case CMD_OTA:
        send_ack("ota");
        sleep_ms(50);          /* let the ack drain through the CH9120 */
        ota_request_update();  /* reboots into bootloader recovery */
        break;
    default:
        send_err("unknown cmd");
        break;
    }
}

int main(void) {
    stdio_init_all();

    /* Let the USB-serial host attach before the banner. */
    sleep_ms(1500);
    printf("\n=== rp2040-eth-panel v%s (CH9120) ===\n", FW_VERSION);

    /* Bring the LED up FIRST as a boot indicator: solid blue once we reach main
     * (so "dark" means hung in crt0/jump, not merely mid-net_init which can take
     * ~20s). Switches to the IP-octet flash once the network is up. */
    status_led_init();
    status_led_solid(0, 0, 60); /* blue: booted, bringing up network */

    buttons_hw_init();
    buttons_init(&s_buttons, s_debounce_ms);
    rings_hw_init();
    const uint16_t nleds[RING_COUNT] = { RING1_NUM_LEDS, RING2_NUM_LEDS };
    rings_init(&s_rings, nleds);
    rings_flush(); /* push a known all-off frame over any power-on garbage */

#ifndef RING_SELFTEST
#define RING_SELFTEST 0
#endif
#if RING_SELFTEST
    /* Panel hardware self-test, no network: cycle pure logical R/G/B on both
     * rings with distinct dwell times (RED 1s, GREEN 2s, BLUE 4s) to verify the
     * color order; print raw button levels; lamp follows button 1. */
    {
        const char *names[3] = {"RED (1s)", "GREEN (2s)", "BLUE (4s)"};
        const uint8_t cols[3][3] = {{255, 0, 0}, {0, 255, 0}, {0, 0, 255}};
        const uint32_t dwell[3] = {1000, 2000, 4000};
        int i = 0;
        absolute_time_t next = get_absolute_time();
        while (true) {
            if (time_reached(next)) {
                printf("[ringtest] intended %s\n", names[i]);
                for (int rg = 0; rg < RING_COUNT; rg++)
                    rings_set(&s_rings, rg, cols[i][0], cols[i][1], cols[i][2], 255);
                next = make_timeout_time_ms(dwell[i]);
                i = (i + 1) % 3;
            }
            rings_flush();
            bool raw[BTN_COUNT];
            buttons_hw_read(raw);
            lamp_hw_set(raw[0]);
            static bool last[BTN_COUNT];
            for (int bi = 0; bi < BTN_COUNT; bi++) {
                if (raw[bi] != last[bi]) {
                    printf("[ringtest] button %d raw %s\n", bi + 1, raw[bi] ? "DOWN" : "UP");
                    last[bi] = raw[bi];
                }
            }
            sleep_ms(2);
        }
    }
#endif

    net_status_t st;
    net_init(&st);

    /* Color = configured IP mode (green = DHCP, amber = static). NOTE: this does
     * NOT indicate a live Ethernet link — the CH9120 exposes no link status to the
     * RP2040, so the LED only reflects "app running + configured mode + last IP". */
    if (st.dhcp_mode) {
        status_led_set_color(0, 40, 0);  /* green: DHCP mode */
    } else {
        status_led_set_color(40, 20, 0); /* amber: static mode */
    }
    status_led_show_octet(st.ip[3]);
    printf("[main] app running (%s, ip .%d) — note: LED does not indicate link state\n",
           st.dhcp_mode ? "DHCP" : "static", st.ip[3]);

    /* We booted far enough to bring the network up -> confirm this image so the
     * bootloader stops counting attempts and won't revert to recovery. */
    if (st.responding) {
        ota_confirm();
    }

    printf("[main] panel up: buttons GP%d/GP%d, lamp GP%d, rings GP%d/GP%d (%d/%d LEDs)\n",
           BUTTON1_PIN, BUTTON2_PIN, LAMP_PIN, RING1_PIN, RING2_PIN,
           RING1_NUM_LEDS, RING2_NUM_LEDS);

    /* Seed the debouncer from the current pin levels BEFORE the loop, so the very
     * first hello (which can fire on the same iteration as the first peer connect)
     * reports the true button state — e.g. a button held across a reboot/OTA. The
     * seeding update emits no edge events (by design); state reaches the host via
     * hello and any later release/press then produces a normal edge. */
    {
        bool raw0[BTN_COUNT];
        buttons_hw_read(raw0);
        buttons_update(&s_buttons, raw0, to_ms_since_boot(get_absolute_time()), NULL, 0);
    }

    bool      peer_was_connected = false;
    char      linebuf[256];
    size_t    linelen = 0;
    bool      discard = false; /* true while skipping an overlong line to its '\n' */
    uint8_t   rxbuf[128];
    btn_event evs[BTN_COUNT * 2];

    while (true) {
        status_led_task();

        /* Hello on every TCP peer connect so the host can resync state. */
        bool peer = net_peer_connected();
        if (peer && !peer_was_connected) {
            net_rx_flush();    /* drop stale bytes left by the previous client */
            send_hello(&st);
            linelen = 0;       /* drop any half-line from a previous connection */
            discard = false;
        }
        peer_was_connected = peer;

        /* Buttons: sample -> debounce -> press/release events to wire + serial. */
        uint32_t now_ms = to_ms_since_boot(get_absolute_time());
        bool raw[BTN_COUNT];
        buttons_hw_read(raw);
        int ne = buttons_update(&s_buttons, raw, now_ms, evs,
                                (int)(sizeof(evs) / sizeof(evs[0])));
        for (int i = 0; i < ne; i++) {
            char line[64];
            send_line(line, proto_fmt_btn(line, sizeof(line), evs[i].id,
                                          evs[i].pressed, now_ms));
            printf("[btn] %d %s\n", evs[i].id, evs[i].pressed ? "down" : "up");
        }

        /* Incoming commands: accumulate bytes, dispatch complete lines. */
        int n = net_read(rxbuf, (int)sizeof(rxbuf));
        for (int i = 0; i < n; i++) {
            char ch = (char)rxbuf[i];
            if (ch == '\n') {
                /* Newline ends a line — or ends an overlong line we were skipping.
                 * Either way, resync to a clean line boundary here. */
                if (!discard) {
                    linebuf[linelen] = '\0';
                    if (linelen > 0) dispatch(linebuf);
                }
                linelen = 0;
                discard = false;
            } else if (discard) {
                /* Mid-overlong-line: keep skipping until the next newline so a
                 * trailing fragment can never be dispatched as a command. */
            } else if (linelen < sizeof(linebuf) - 1) {
                linebuf[linelen++] = ch;
            } else {
                /* Overflow: enter discard until the next newline (emit one err). */
                discard = true;
                linelen = 0;
                send_err("line too long");
            }
        }

        rings_flush();
        sleep_ms(2);
    }
}

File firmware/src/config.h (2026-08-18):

/*
 * config.h — compile-time defaults for rp2040-eth-panel.
 *
 * Board: Waveshare RP2040-ETH. Ethernet is provided by a CH9120 UART-to-Ethernet
 * bridge (NOT a W5500/SPI). The RP2040 configures the CH9120 over UART1 in config
 * mode, then streams the TCP payload over the same UART at the data baud.
 *
 * Panel hardware: two momentary buttons (button 1 is illuminated), one lamp
 * output for button 1's illumination, and two WS2812 LED rings.
 */
#ifndef PANEL_CONFIG_H
#define PANEL_CONFIG_H

#define FW_VERSION "1.0.3"

/* ---- CH9120 Ethernet bridge (UART1) — fixed by the Waveshare board ---- */
#define CH9120_UART       uart1
#define CH9120_PIN_TX     20 /* RP2040 UART1 TX -> CH9120 RXD */
#define CH9120_PIN_RX     21 /* RP2040 UART1 RX <- CH9120 TXD */
#define CH9120_PIN_CFG    18 /* config enable: LOW = config mode */
#define CH9120_PIN_RST    19 /* reset, active LOW */
#define CH9120_PIN_TCPS   17 /* TCP status: LOW = peer connected */
#define CH9120_CFG_BAUD   9600
#define CH9120_DATA_BAUD  115200

/* ---- Network role + addressing ---- */
#define NET_MODE_TCP_SERVER 0
#define NET_MODE_TCP_CLIENT 1
#define NET_MODE_UDP_SERVER 2
#define NET_MODE_UDP_CLIENT 3

#define NET_MODE        NET_MODE_TCP_SERVER /* device listens; host connects */
/* IP mode for the deployment. 1 = DHCP, 0 = static (the addresses below).
 * There is no auto-fallback: the CH9120 gives no link/DHCP status the RP2040 can
 * read, so a failed DHCP can't be detected — choose the right mode here. */
#define NET_USE_DHCP    1

/* Static addressing — used when NET_USE_DHCP = 0. (With DHCP these are ignored;
 * the leased IP is read back from the CH9120 and shown on serial / the LED octet.) */
#define NET_LOCAL_IP    { 10, 74, 31, 251 }   /* set for your subnet if using static */
#define NET_SUBNET      { 255, 255, 252, 0 }  /* /22 */
#define NET_GATEWAY     { 10, 74, 28, 1 }
#define NET_LOCAL_PORT  5005

/* Target (used only in TCP/UDP client mode — device dials this host). */
#define NET_TARGET_IP   { 192, 168, 1, 100 }
#define NET_TARGET_PORT 5005

/* ---- Application pins ----
 * NOTE: the RP2040-ETH MINI board only breaks out GPIO0-9, 22, 26, 27, 28 on its
 * 24-pin header (GP10-15 and GP25 are NOT on the header; GP16-21 are the CH9120).
 * All panel pins below are header-accessible. Silk labels are GPn. */
#define RING1_PIN      2  /* WS2812 ring 1 data (header pin 21) */
#define RING2_PIN      3  /* WS2812 ring 2 data (header pin 20) */
#define BUTTON1_PIN    4  /* illuminated button, to GND, internal pull-up (pin 19) */
#define BUTTON2_PIN    5  /* plain button, to GND, internal pull-up (pin 18) */
#define LAMP_PIN       6  /* button 1 illumination, on/off output (header pin 16) */
#define STATUS_LED_PIN 25 /* onboard WS2812 (GP25, not on header) */

/* ---- WS2812 rings ----
 * Color order is per-chain: the ONBOARD GP25 WS2812 on this board latches RGB
 * (verified by self-test in the keypad project — status_led.c sends RGB), but
 * standard WS2812B ring modules latch GRB. If colors come out swapped, build
 * with -DRING_SELFTEST=1, watch the announced colors, and flip this. */
#define RING1_NUM_LEDS 16
#define RING2_NUM_LEDS 16
#define RING_MAX_LEDS  16          /* max(RING1_NUM_LEDS, RING2_NUM_LEDS) */
#define RING_COLOR_ORDER_GRB 1     /* 1 = GRB (standard WS2812B), 0 = RGB */

/* Power-on ring state: off, full brightness scale so the first color command
 * with no explicit brightness shows at full. */
#define RING_DEFAULT_BRIGHTNESS 255

/* ---- Buttons ---- */
#define BUTTON_COUNT            2
#define DEBOUNCE_MS_DEFAULT     30 /* runtime-overridable via the `config` command */

#endif /* PANEL_CONFIG_H */

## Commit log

2026-06-12 Scaffold rp2040-eth-panel: port OTA/net/status-LED fundamentals from rp2040-eth-keypad; new buttons/rings/protocol modules + panel main
2026-06-12 Firmware builds; host test harness (34 green), ROS2 Humble driver, tools, docs
    - buttons: first-sample seeding so boot-held buttons emit no phantom edge
    - main: line framing + full command dispatch (ring/lamp/config/ping/ota), hello on TCP connect
    - rings: pure state/scaling/packing on pio1 sm0/sm1, GRB default with RING_SELFTEST
    - ros2/panel_driver: latched button topics, ColorRGBA a=brightness, desired-state resync
    - tools: panel_live (interactive), bidirectional mock_panel_server, panel_watch
2026-06-12 Fix confirmed review findings (firmware) + bump to v1.0.1
    Firmware (ship in OTA image):
    - net.c: IRQ-driven RX ring buffer (2048B) so loop-blocking writes can't drop
    inbound bytes (32B UART FIFO = only ~2.8ms at 115200); net_rx_flush() on reconnect
    - main.c: seed debouncer before loop so a boot-held button is reported in hello;
    discard-state for overlong lines (tail can no longer be dispatched as a command);
    rings_flush keeps dirty on render failure
    - buttons.c: only commit stable flip when the edge can be emitted (no state/event desync)
    - protocol.c: find_key scans past value-string collisions to the real key
    - status_led.c/rings_hw.c: enforce WS2812 >=280us latch gap (boot-blue + sel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
    [Casing.FCStd, Casing.stl]
2026-06-12 Fix confirmed review findings (ROS driver)
    - destroy_node: shut down socket + join reader thread (no leaked thread / clean shutdown)
    - _send: on write failure, shutdown the socket so the reader reconnects and
    _resync replays the cache onto clean framing (a partial write no longer corrupts the stream)
    - latched button QoS depth 1 -> 10 so a rapid press/release burst isn't coalesced
    - a=0 brightness warning is now warn-once (was firing on every legitimate OFF)
    Verified live against the device (192.0.2.50): connect, hello fw=1.0.1,
    latched button state published, ColorRGBA ring + Bool lamp commands acked.
    15 driver tests + colcon build green.
2026-06-12 Add standalone single-file ROS 2 example driver
    examples/standalone_panel_driver.py: ~100-line self-contained rclpy node, run
    directly (python3 examples/standalone_panel_driver.py <ip>) with no colcon build,
    no package install, no launch file — just source /opt/ros/humble/setup.bash.
    Publishes /button{1,2}_pressed (Bool); subscribes /ring{1,2}_color (ColorRGBA,
    a=brightness) and /button1_light (Bool). Inlines the tiny JSON protocol so it has
    no dependency on the panel_driver package. Verified live against the device
    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
2026-06-12 Bump to v1.0.2 (OTA-deployed over Ethernet, USB disconnected)
    Verified the OTA-only update path with no USB attached: device at 192.0.2.50
    driven into recovery, 45684B image streamed + CRC-verified, rebooted into v1.0.2
    (confirmed via hello + ping). No firmware code change vs v1.0.1 — version bump only.
    [config.h]
2026-06-12 Fix standalone example: clear inherited socket timeout so reader survives idle
    socket.create_connection(timeout=5) leaves a 5s timeout on the returned socket;
    recv() then raised socket.timeout (OSError) after 5s with no button activity,
    and read_loop's 'except OSError: break' killed the reader thread — so the example
    published the hello, then silently stopped receiving/publishing button events.
    Add self.sock.settimeout(None) after connect so recv blocks until data arrives.
    Verified live: both /button{1,2}_pressed stream press/release after >8s idle.
2026-06-12 Fix documentation accuracy issues flagged by review
    - protocol.h: err example said 'bad ring id'; firmware emits 'bad ring cmd'
    - ros2 README: '2 illuminated buttons' -> only button 1 is illuminated
    - DESIGN.md: CH9120 commit listed a phantom 0x5e byte; only 0x0d/0x0e are sent
    - OTA.md: referenced nonexistent host fn wait_for_recovery -> ensure_recovery
    - README: document the new examples/standalone_panel_driver.py (was unlisted)
    Comment/doc-only; no binary change (deployed v1.0.2 unaffected). 34 host tests green.
2026-06-12 Record hardware bring-up results in BRINGUP.md
    Bring-up complete and verified 2026-06-12 (device 192.0.2.50, v1.0.2):
    provision, boot banner, buttons (both), lamp, rings, DHCP, protocol, OTA over
    Ethernet (USB-free), and ROS driver all PASS. Notes which formal sub-steps
    (RING_SELFTEST dwell check, LED octet, interrupted-push on hw) were not separately
    run vs covered by the sim suite. Carries the single-client / zombie-process gotcha.
    [Casing.FCStd, lid.stl]
2026-08-18 Add {"cmd":"hello"} request verb; drivers request hello on connect (v1.0.3)
    Some CH9120 batches never assert the TCPS status pin (observed on unit
    REDACTED-SERIAL: pin actively driven but stays HIGH with a live TCP
    connection), so the edge-triggered connect-time hello never fires and
    hosts get no state resync. Firmware now answers {"cmd":"hello"} with the
    hello line, and the ROS driver, standalone example, and mock server
    request it right after connecting instead of relying on the unsolicited
    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
2026-08-18 Make the driver's hello request a delayed fallback, not a connect race
    Live test against a TCPS-working unit exposed a race in the previous
    commit: the firmware flushes its RX buffer on the TCPS connect edge, so
    a hello request sent in the same instant as the connect arrives
    truncated and the device answers {"t":"err","msg":"no cmd"} on every
    connect. The ROS driver now waits ~1 s for the device's unsolicited
    connect-time hello and only requests one if it hasn't arrived; the
    standalone example uses a short grace sleep instead.
    Verified live: TCPS-working unit (192.0.2.50, MAC
    AA:BB:CC:12:34:56) — single hello 11 ms after connect, no error;
    TCPS-dead behavior via mock — fallback request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
2026-08-20 Add RX-fed liveness keepalive to the ROS driver; auto-recover dead links
    The CH9120 silently drops a displaced client (no FIN/RST), stranding the
    driver on a half-open socket: recv() times out quietly forever and sends
    vanish into the local TCP buffer, so the driver looked connected while
    the device stopped listening — recoverable only by manual restart.
    The driver now pings after keepalive_period (2 s) of RX silence and
    declares the connection dead after liveness_timeout (6 s) without
    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
2026-08-20 Add CAD for the one-button panel variant
    New top casing (single button, no front lit button), lid with
    stabilizer, and updated FreeCAD source. Ignore FreeCAD .FCBak
    auto-backups and drop the previously tracked one.
    [Casing 1 button.stl, Casing.FCStd, Top Casing.step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]
2026-08-20 Scrub personal info for public release; add changelog
    Replace the maintainer email with the GitHub noreply address, replace
    bench-network IPs and device MACs in docs and examples with
    documentation-range placeholders (192.0.2.x, AA:BB:CC:12:34:56), and add
    CHANGELOG.md covering v1.0.0 through v1.0.3.
